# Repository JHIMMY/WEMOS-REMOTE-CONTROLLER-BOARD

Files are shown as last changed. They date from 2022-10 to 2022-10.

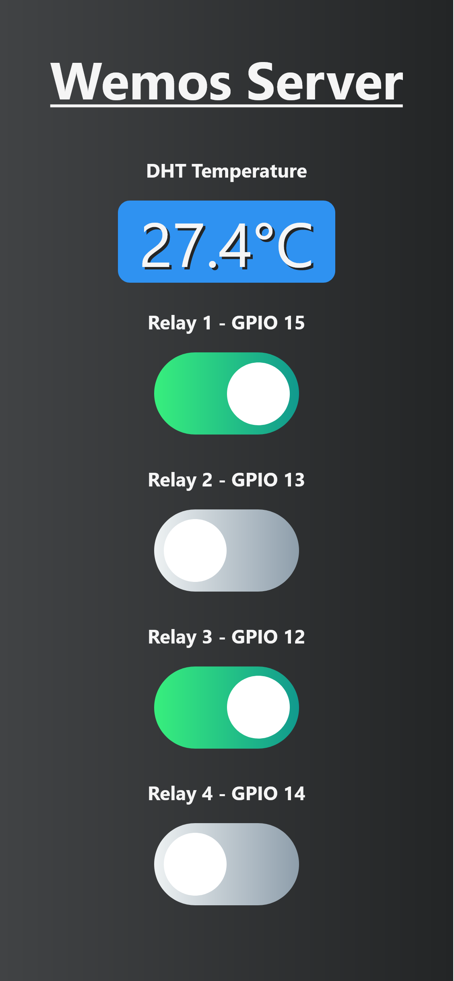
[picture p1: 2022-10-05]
Screen Shot 2022-10-03 at 23.22.45.png

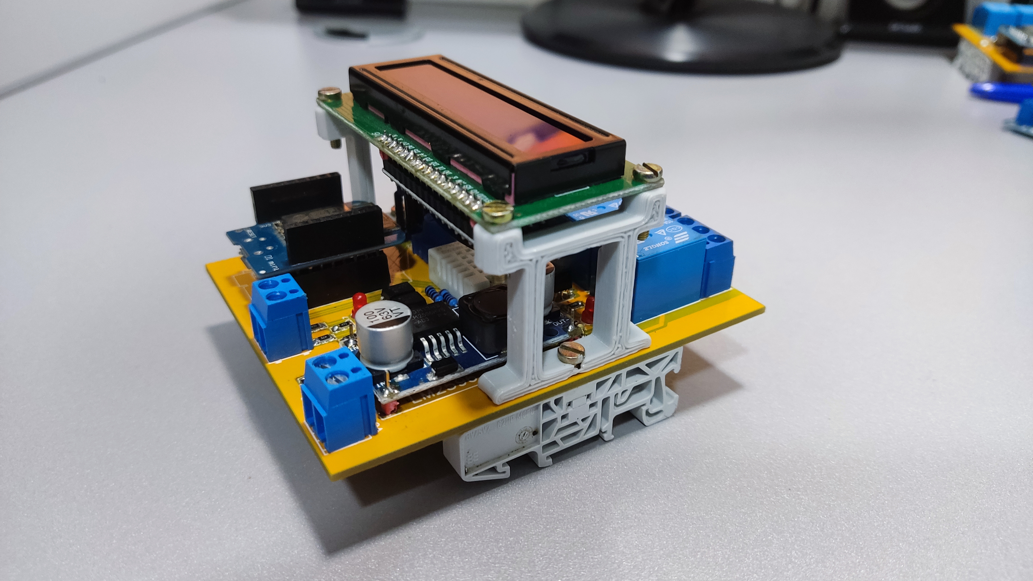
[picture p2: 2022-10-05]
1664852861336.jpg

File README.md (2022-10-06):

# WEMOS-REMOTE-CONTROLLER-BOARD
ESP Board Picture
En este proyecto veremos cómo realizar un controlador remoto con entradas y salidas compatibles con 12V y 24V de corriente continua, que será compatible con el esp8266 y también con el esp32. Veremos cómo crear un servidor Web Asíncrono y correrlo desde el microcontrolador, lo que nos permitirá controlarlo mediante peticiones desde cualquier dispositivo conectado a la red local (PC, Celular, Tablet). Lo bueno es que no dependeremos de ningún servicio de terceros y ademas podemos escalarlo para controlarlo desde cualquier parte del mundo.

Pueden descargar los archivos gerber o directamente pedir esta pcb: 
https://www.pcbway.com/project/shareproject/ESP8266_ESP32_REMOTE_CONTROLLER_BOARD_797f1ed0.html

Y tienen mas información del funcionamiento y código en este video: 
https://youtu.be/-LM8jwtAY4E

Lista de materiales:
3pza resistencia SMD 1206 330R
6pza resistencia SMD 1206 4k7
6pza resistencia SMD 1206 10k
2pza PC817 "octoacoplador"
7pza led de 3mm
1pza Modulo DC-DC LM2596
4pza 2N2222
4pza 1N4148
4pza Rele bobina 5v
4pza resistencia de 1k 1/4W
2pza resistencia de 10k 1/4W
1pza DTH11 o DTH22
1pza Potenciometro 10k azul
4pza Bornera de 3P
2pza Bornera de 2P
1pza regleta pin Macho
1pza regleta pin Hembra
2pza tornillo M3x12mm

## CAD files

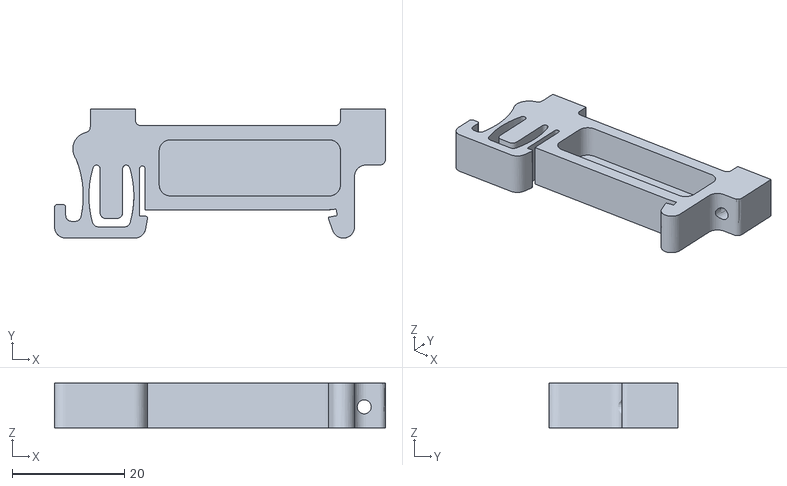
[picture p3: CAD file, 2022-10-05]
Riel_Din_PCB.stl
58.9 x 23.0 x 8.00

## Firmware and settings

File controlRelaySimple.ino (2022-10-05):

#define DEBUG   // habilitar debugging
#include "debugUtils.h"

// pines relays
const uint8_t rel1 = 15;  // D8
const uint8_t rel2 = 13;  // D7
const uint8_t rel3 = 12;  // D6
const uint8_t rel4 = 14;  // D5

// arreglo de relés
const uint8_t relayCount = 4;
const uint8_t relays[relayCount] = {rel1, rel2, rel3, rel4};
const byte softDelay = 140;

void setup() {
  // configuración
  for (uint8_t i = 0; i < relayCount; i++)
    pinMode(relays[i], OUTPUT);

  Serial.begin(115200);

}

void loop()
{
  delay(2000);
  
  // activar relés
  controlRelays(true);
  DEBUG_PRINT("Relays activados");

  delay(2000);

  // desactivar relés
  controlRelays(false);
  DEBUG_PRINT("Relays desactivados");
}

void controlRelays(bool enable)
{
  for (byte i = 0; i < relayCount; i++)
  {
    digitalWrite(relays[i], enable ? HIGH : LOW); // Si es low level trigger invertir
    delay(softDelay);
  }
}
